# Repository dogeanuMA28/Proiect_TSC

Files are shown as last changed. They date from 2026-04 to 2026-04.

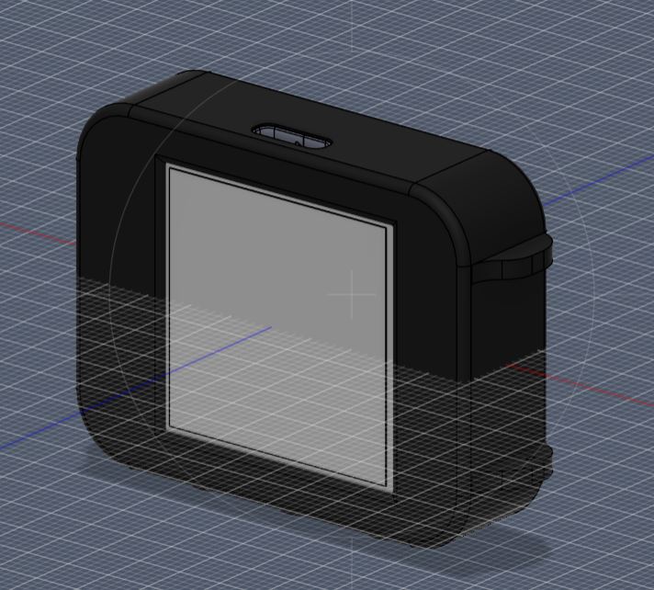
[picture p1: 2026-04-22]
Images/ceas.JPG

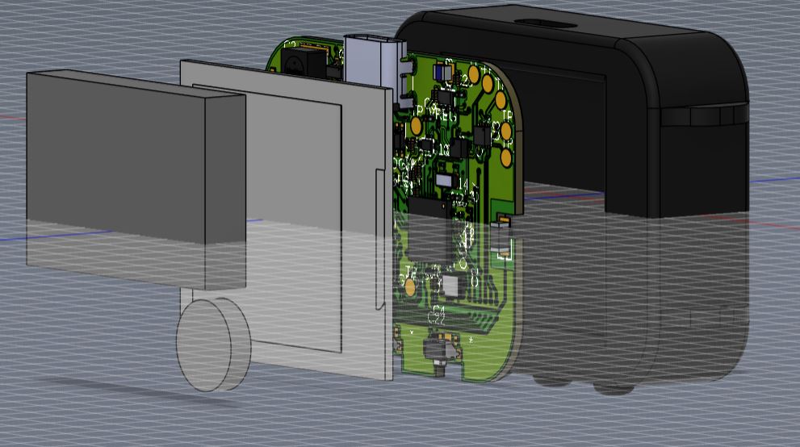
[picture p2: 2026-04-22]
Images/muie_TSC.JPG

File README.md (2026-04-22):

# Proiect_TSC

DIAGRAMA

## BOM(Bill of Materials)
| Componentă | Producator | Cantitate | Link achizitie | Datasheet |
| :--- | :--- | :---: | :--- | :--- |
| **nRF52840** | Nordic Semiconductor | 1 | [Link](https://jlcpcb.com/partdetail/NordicSemicon-NRF52840_QFAA_FR/C3606918) | [Datasheet](https://infocenter.nordicsemi.com/pdf/nRF52840_PS_v1.1.pdf) |
| **BMA423** | Bosch | 1 | [Link](https://jlcpcb.com/partdetail/BoschSensortec-BMA423/C189517) | [Datasheet](https://www.bosch-sensortec.com/media/boschsensortec/downloads/datasheets/bst-bma423-ds004.pdf) |
| **BQ25180YBGR** | Texas Instruments | 1 | [Link](https://jlcpcb.com/partdetail/TexasInstruments-BQ25180YBGR/C3682423) | [Datasheet](https://www.ti.com/lit/ds/symlink/bq25180.pdf) |
| **MAX17048G+T10** | Analog Devices | 1 | [Link](https://jlcpcb.com/partdetail/2777647-MAX17048GT10/C2682616) | [Datasheet](https://datasheets.maximintegrated.com/en/ds/MAX17048-MAX17049.pdf) |
| **DRV2605YZFR** | Texas Instruments | 1 | [Link](https://jlcpcb.com/partdetail/TexasInstruments-DRV2605YZFR/C81079) | [Datasheet](https://www.ti.com/lit/ds/symlink/drv2605.pdf) |
| **RT6160AWSC** | Richtek | 1 | [Link](https://jlcpcb.com/partdetail/RichtekTech-RT6160AWSC/C7065276) | [Datasheet](https://www.richtek.com/assets/product_file/RT6160/DS6160-03.pdf) |
| **2450AT18B100E** | Johanson | 1 | [Link](https://jlcpcb.com/partdetail/JohansonDielectrics-2450AT18B100E/C2917717) | [Datasheet](https://www.johansontechnology.com/datasheets/2450AT18B100E/2450AT18B100E.pdf) |
| **744043680 (L4)** | Wurth | 1 | [Link](https://jlcpcb.com/partdetail/WurthElektronik-744043680/C2045671) | [Datasheet](https://www.we-online.com/catalog/datasheet/744043680.pdf) |
| **FTC252012SR47** | CMT | 1 | [Link](https://jlcpcb.com/partdetail/6763488-FTC252012SR47MBCA/C5832368) | [Datasheet](https://product.tdk.com/en/system/files/dam/doc/product/inductor/inductor/smd/catalog/inductor_commercial_power_ftc252012s_en.pdf) |
| **503480-2400** | Molex | 1 | [Link](https://jlcpcb.com/partdetail/MOLEX-5034802400/C122434) | [Datasheet](https://www.molex.com/pdm_docs/sd/5034802400_sd.pdf) |
| **USB-C 16P** | Kinghelm | 1 | [Link](https://jlcpcb.com/partdetail/Shenzhen_KinghelmElec-KH_TYPE_C16P/C709357) | [Datasheet](https://datasheet.lcsc.com/lcsc/2112151030_Kinghelm-KH-TYPE-C-16P_C2930266.pdf) |
| **EVP-AKE31A** | Panasonic | 3 | [Link](https://jlcpcb.com/partdetail/PANASONIC-EVPAKE31A/C569760) | [Datasheet](https://industrial.panasonic.com/ww/products/pt/tactile-sw/models/EVPAKE31A) |
| **USBLC6-2SC6Y** | STMicroelectronics | 1 | [Link](https://jlcpcb.com/partdetail/STMicroelectronics-USBLC62SC6Y/C2969755) | [Datasheet](https://www.st.com/resource/en/datasheet/usblc6-2.pdf) |
| **MBR0530** | JCET | 3 | [Link](https://jlcpcb.com/partdetail/78464-MBR0530/C77336) | [Datasheet](https://www.onsemi.com/pdf/datasheet/mbr0530t1-d.pdf) |
| **SI1308EDL** | Vishay | 1 | [Link](https://jlcpcb.com/partdetail/VishayIntertech-SI1308EDL_T1GE3/C469327) | [Datasheet](https://www.vishay.com/docs/72013/si1308edl.pdf) |
| **DMG2305UX-7** | TECH PUBLIC | 1 | [Link](https://jlcpcb.com/partdetail/TECHPUBLIC-DMG2305UX/C2940629) | [Datasheet](https://www.diodes.com/assets/Datasheets/DMG2305UX.pdf) |
| **GRM0335C1E101JA01D** | Murata Electronics | 10 | [Link](https://jlcpcb.com/partdetail/MurataElectronics-GRM0335C1E101JA01D/C76917) | [Datasheet](https://docs.rs-online.com/3c16/A700000008615521.pdf) |
| **Condensatoare(0402)** | Samsung Electro-Mechanics | 21 | [Link](https://jlcpcb.com/partdetail/Samsung_Electro_Mechanics-CL05A105KB5NQNC/C52923) | [Datasheet](https://www1.futureelectronics.com/doc/Samsung%20Electro-Mechanics/CL05A105KA5NQNC-SMP.pdf) |
| **Condensatoare(0201)** | Samsung Electro-Mechanics | 17 | [Link](https://jlcpcb.com/partdetail/Murata_Electronics-GRM033R61A104KE84D/C1619) | [Datasheet](https://docs.rs-online.com/3c16/A700000008615521.pdf) |
| **Rezistente(0201)** | UNI-ROYAL | 17 | [Link](https://jlcpcb.com/parts/componentSearch?searchTxt=0201%20resistor) | [Datasheet](https://jlcpcb.com/api/file/downloadByFileSystemAccessId/8590910972175327232) |

## Functionalitati hardware

### LiPo Charger
Circuitul incarca o baterie LiPo (Lithium-Polymer), controland tensiunea si curentul pentru a preveni supraincarcarea, deteriorarea sau riscul de incendiu. Comunica folosind I2C cu nRF52840.

### Fuel Gauge
Circuitul masoara nivelului bateriei. El alerteaza ceasul cand nivelul bateriei este scazut. Comunica folosind I2C cu nRF52840.

### DC/DC
Circuitul alimenteaza si transforma tensiunea in alte tensiuni stabile, necesare pentru alte componente ale ceasului. Comunica folosind 
I2C cu nRF52840.

### E-Paper Connector
Circuitul este conexiunea la ecranul E-Paper. Comunica folosind SPI cu nRF52840.

### E-Paper Drive Circuit
Circuit de comanda care genereaza si controleaza tensiunile si semnalele necesare pentru a actualiza un afisaj E-Paper. Gestioneaza
procesul de schimbare al pixelilor pentru a afisaj.

### USB-C Connector
Circuitul reprezintă mufa USB. Asigura alimentare, transfer de date si semnal video între dispozitive.

### ESD Protection
Circuitul protejează electronica sensibila din USB impotriva descarcarilor electrostatice bruste, limitand tensiunile mari și devierea
curentului către masa pentru a preveni deteriorarea componentelor.

### SWD
Circuitul este folosit pentru debugging. Poate fi conectat la JTAG.

### Haptic Driver
Circuitul genereaza vibratii, transformand semnale digitale din microcontroler in impulsuri precise de vibratie. Comunica folosind I2C cu 
nRF52840.

### IMU
Circuitul masoara acceleratia si directia ceasului. Comunica folosind I2C cu nRF52840.

## nRF52840 - descrierea pinilor
* **P$AD12 (EPD_BUSY)** - conexiune care arata daca ecranul este ocupat (E-Paper Display)
* **P$AD10 (EPD_DC)** - conexiune data/command(E-Paper Display)
* **P$K2 (EPD_CS)** - conexiune chip select(E-Paper Display)
* **P$AD12 (EPD_RST)** - conexiune pentru resetare(E-Paper Display)
* **P$A12 (SCK)** - clock SPI(E-Paper Display)
* **P$P13 (MOSI)** - data(master out slave in) SPI(E-Paper Display).
* **P$Y23 (P1.01)** - conexiune circuit de comanda
* **P$AD8 (P0.13)** - buton din stanga
* **P$AC9 (P0.14)** - buton din mijloc
* **P$W24 (P1.02)** - buton din dreapta
* **P$AD6 (D+)** - traseu diferențial pozitiv pentru ESD Protection
* **P$AD4 (D-)** - traseu diferențial negativ pentru ESD Protection.
* **P$AD2 (VBUS)** - conexiune VBUS(USB)
* **P$U1 (HAPTIC_EN)** - conexiune enable/disable(Haptic Driver)
* **P$T2 (PMIC_INT)** - intrerupere(LiPo Battery)
* **P$P2 (IMU_INT2)** - intrerupere(IMU)
* **P$N1 (IMU_INT1)** - intrerupere(IMU)
* **P$M2 (SCL)** - clock I2C
* **P$L1 (SDA)** - data I2C
* **P$J24 (ALERT)** - conexiune cu alerta(Fuel Gauge)
* **P$AD22 (SWO)** - conexiune pentru debug(TP_SWO)
* **P$AC13 (RESET)** - conexiune pentru resetarea componentei(TP_RESET, SWD)
* **P$AA24 (SWDCLK)** - conexiune pentru debug(SWD)
* **P$AC24 (SWDIO)** - conexiune input/output(SWD)
* **P$F2 și P$D2** - ceasul de 32 kHz
* **P$A23 și P$A24** - ceasul de 32 MHz
* **P$H23, P$F23** - conexiune antena antenă.

## Rutare

Cablajul imprimat (PCB) este realizat pe **4 straturi (4-layer stack-up)**:
* **Top** – rutarea semnalelor si plasarea componentelor
* **GND** – plan de masa continuu (GND)
* **Power** – plan de alimentare
* **Bottom** – rutarea semnalelor

**DC/DC**, **LiPo Charger** si **Fuel Gauge** le-am pozitionat apropiate pentru a oferi un transfer transfer de putere cat mai eficient.
**E-Paper Drive Circuit** a fost izolat in partea de stanga sus(dar tot aproape de **E-Paper Display Connector**) pentru a evita zgomotele
care ar putea fi produse de bobina si care ar putea afecta semnalel SPI, busy sau reset din **E-Paper Display Connector**.
**Haptic Driver** este tinut la distanta de IMU pentru a preveni interferentele din cauza vibratiilor.

## Erori

### via-smd
Am acceptat erorile astea pentru a majoritatea provin din faptul ca am facut vi-in-pad pentru GND.

### smd-via
Le-am acceptat pentru ca fie vin din acelasi motiv ca erorile de mai sus fie de la nRF52840 pentru ca a trebuit
sa pun via-in-pad pentru a conecta cu intrarile de mai din interior.

### solid-poligon-shape
Sunt erori de la butoane. Cred ca este de la disignul lor si nu le pot rezolva.

### via-via
Acestea provin tot de la nRF52840, tot pe intrarile de mai din interior. Le-am acceptat pentru ca altfel nu puteam
conecta firele pentru ca spatiul era mult prea mic.

### via, drill size
Tot ca mai sus. Am fost nevoit sa folosesc via pentru a conecta firele. Spatiul fiid prea mic a trabuit sa
folosesc drill size mai mic de 0.3mm cum precizeaza rule-urile.

### smd-hole
Problema vine de la USB. Tot designul este prblema. Nu am stiut cum sa rezolv aceasta problema fara sa modific
efectiv designul componentei.

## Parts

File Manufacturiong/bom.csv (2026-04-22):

Reference Designators | Quantity | Description | Package | Value | Manufacturer | Manufacturer Part Number | Vendor | Vendor Part Number | Top/Bottom
 | 1 | Board | Board
ANT1 | 1 | Antennas 2.45GHz ANTENNA | 2450AT18B100E_ANTC3216X140N | 2450AT18B100E |  |  |  |  | Top
C1 | 1 | Generic chip capacitor | NORDIC_NRF_3_RESC0201_L | 12pF |  |  |  |  | Top
C1-EP-DR | 1 | Generic chip capacitor | NORDIC_NRF_3_RESC0402_L | 10uF |  |  |  |  | Top
C2 | 1 | Generic chip capacitor | NORDIC_NRF_3_RESC0201_L | 12pF |  |  |  |  | Top
C2-EP-DR | 1 | Generic chip capacitor | NORDIC_NRF_3_RESC0402_L | 4.7uF/25V |  |  |  |  | Top
C3 | 1 | Generic chip capacitor | NORDIC_NRF_3_RESC0201_L | 1pF |  |  |  |  | Top
C4 | 1 | Generic chip capacitor | NORDIC_NRF_3_RESC0201_L | 1pF |  |  |  |  | Top
C5 | 1 | Generic chip capacitor | NORDIC_NRF_3_RESC0201_L | 100nF |  |  |  |  | Top
C6 | 1 | Generic chip capacitor | NORDIC_NRF_3_RESC0402_L | 4.7uF |  |  |  |  | Top
C7 | 1 | Generic chip capacitor | NORDIC_NRF_3_RESC0201_L | 100nF |  |  |  |  | Top
C8 | 1 | Generic chip capacitor | NORDIC_NRF_3_RESC0201_L | 100nF |  |  |  |  | Top
C9 | 1 | Generic chip capacitor | NORDIC_NRF_3_RESC0201_L | 820pF |  |  |  |  | Top
C10 | 1 | Generic chip capacitor | NORDIC_NRF_3_RESC0201_L | N.C. |  |  |  |  | Top
C11 | 1 | Generic chip capacitor | NORDIC_NRF_3_RESC0201_L | 100pF |  |  |  |  | Top
C12 | 1 | Generic chip capacitor | NORDIC_NRF_3_RESC0201_L | 100nF |  |  |  |  | Top
C13 | 1 | Generic chip capacitor | NORDIC_NRF_3_RESC0201_L | N.C. |  |  |  |  | Top
C14 | 1 | Generic chip capacitor | NORDIC_NRF_3_RESC0402_L | 4.7uF |  |  |  |  | Top
C15 | 1 | Generic chip capacitor | NORDIC_NRF_3_RESC0402_L | 1.0uF |  |  |  |  | Top
C16 | 1 | Generic chip capacitor | NORDIC_NRF_3_RESC0201_L | 47nF |  |  |  |  | Top
C17 | 1 | Generic chip capacitor | NORDIC_NRF_3_RESC0201_L | 12pF |  |  |  |  | Top
C18 | 1 | Generic chip capacitor | NORDIC_NRF_3_RESC0201_L | 12pF |  |  |  |  | Top
C19 | 1 | Generic chip capacitor | NORDIC_NRF_3_RESC0201_L | 100nF |  |  |  |  | Top
C20 | 1 | Generic chip capacitor | NORDIC_NRF_3_RESC0402_L | 4.7uF |  |  |  |  | Top
C21 | 1 | Generic chip capacitor | NORDIC_NRF_3_RESC0402_L | 4.7uF |  |  |  |  | Top
C22 | 1 | Generic chip capacitor | NORDIC_NRF_3_RESC0201_L | N.C. |  |  |  |  | Top
C23 | 1 | Check availability | NORDIC_NRF_3_RESC0201_L | 0.1uF |  |  |  |  | Top
C24 | 1 | Generic chip capacitor | NORDIC_NRF_3_RESC0402_L | 10uF |  |  |  |  | Top
C25 | 1 | Generic chip capacitor | NORDIC_NRF_3_RESC0402_L | 22uF |  |  |  |  | Top
C27 | 1 | Check availability | NORDIC_NRF_3_RESC0201_L | 0.1uF |  |  |  |  | Top
C29 | 1 | Check availability | NORDIC_NRF_3_RESC0201_L | 1uF |  |  |  |  | Top
C30 | 1 | Check availability | NORDIC_NRF_3_RESC0201_L | 1uF |  |  |  |  | Top
C31 | 1 | Check availability | NORDIC_NRF_3_RESC0201_L | 1uF |  |  |  |  | Top
C32 | 1 | Check availability | NORDIC_NRF_3_RESC0201_L | 1uF |  |  |  |  | Top
C33 | 1 | Generic chip capacitor | NORDIC_NRF_3_RESC0402_L | 22uF |  |  |  |  | Top
C34 | 1 | Check availability | NORDIC_NRF_3_RESC0201_L | 0.1uF |  |  |  |  | Top
C37 | 1 | Check availability | NORDIC_NRF_3_RESC0201_L | 1uF |  |  |  |  | Top
C38 | 1 | Check availability | NORDIC_NRF_3_RESC0201_L | 1uF |  |  |  |  | Top
C39 | 1 | Generic chip capacitor | NORDIC_NRF_3_RESC0402_L | 10uF |  |  |  |  | Top
C42 | 1 | Check availability | NORDIC_NRF_3_RESC0201_L | 0.1uF |  |  |  |  | Top
C43 | 1 | Generic chip capacitor | NORDIC_NRF_3_RESC0402_L | 4.7uF |  |  |  |  | Top
D2 | 1 | ON SEMICONDUCTOR - MBR0530 - DIODE, SCHOTTKY, 0.5A, 30V, SOD-123 | ESP32_C6_LIBRARY_5_SOD3716X135N | MBR0530 |  |  |  |  | Top
D3 | 1 | Low Cap. ESD Protection Auto SOT-23-6 STMicroelectronics USBLC6-2SC6Y, Dual Uni-Directional TVS Diode Array, 6-Pin SOT-23 | ESP32_C6_LIBRARY_3_SOT95P280X145-6N | USBLC6-2SC6Y |  |  |  |  | Top
D4 | 1 | ON SEMICONDUCTOR - MBR0530 - DIODE, SCHOTTKY, 0.5A, 30V, SOD-123 | ESP32_C6_LIBRARY_5_SOD3716X135N | MBR0530 |  |  |  |  | Top
D5 | 1 | ON SEMICONDUCTOR - MBR0530 - DIODE, SCHOTTKY, 0.5A, 30V, SOD-123 | ESP32_C6_LIBRARY_5_SOD3716X135N | MBR0530 |  |  |  |  | Top
EPD_C1 | 1 | Generic chip capacitor | NORDIC_NRF_3_RESC0402_L | 1uF/50V |  |  |  |  | Top
EPD_C2 | 1 | Generic chip capacitor | NORDIC_NRF_3_RESC0402_L | 1uF/50V |  |  |  |  | Top
EPD_C5 | 1 | Generic chip capacitor | NORDIC_NRF_3_RESC0201_L | 0.1uF/50V |  |  |  |  | Top
EPD_C6 | 1 | Generic chip capacitor | NORDIC_NRF_3_RESC0402_L | 1uF/50V |  |  |  |  | Top
EPD_C7 | 1 | Generic chip capacitor | NORDIC_NRF_3_RESC0402_L | 1uF/50V |  |  |  |  | Top
EPD_C8 | 1 | Generic chip capacitor | NORDIC_NRF_3_RESC0402_L | 1uF/50V |  |  |  |  | Top
EPD_C9 | 1 | Generic chip capacitor | NORDIC_NRF_3_RESC0402_L | 1uF/50V |  |  |  |  | Top
EPD_C10 | 1 | Generic chip capacitor | NORDIC_NRF_3_RESC0402_L | 1uF/50V |  |  |  |  | Top
EPD_C11 | 1 | Generic chip capacitor | NORDIC_NRF_3_RESC0402_L | 1uF/50V |  |  |  |  | Top
EPD_C12 | 1 | Generic chip capacitor | NORDIC_NRF_3_RESC0402_L | 1uF/50V |  |  |  |  | Top
IC1 | 1 | Charger IC Lithium Ion/Polymer, Lithium Iron Phosphate 8-DSBGA (1.6x1.1) | BQ25180YBGR_BGA8C40P2X4_100X155X50 | BQ25180YBGR |  |  |  |  | Top
IC2 | 1 | Haptic Driver for ERM/LRA with Built-In Library and Smart Loop Architecture | DRV2605YZFR_BGA9C50P3X3_144X144X62-HAPTIC | DRV2605YZFR |  |  |  |  | Top
IC3 | 1 | Accelerometers Triaxial low-g 12bit Acceleration Sensor | IMU_BMA423 | BMA423_BMA423 |  |  |  |  | Top
IC9 | 1 | Buck-Boost Regulator Positive Output Step-Up/Step-Down I2C DC-DC Controller IC 15-WL-CSP (BSC) (1.4x2.3) | RT6160AWSC_BGA15C40P3X5_140X230X60 | RT6160AWSC |  |  |  |  | Top
J1 | 1 | FFC & FPC Connectors 0.5mm FPC RA SMT Dual Contact 24Ckt | 503480-2400 | 503480-2400 |  |  |  |  | Top
J2 | 1 | CABLE ADAPTER 6 POS | TC2030-IDC_TC2030IDC | TC2030-IDC |  |  |  |  | Top
J4 | 1 | Check availability | KH-TYPE-C-16P_KINGHELM_KH-TYPE-C-16P | KH-TYPE-C-16P |  |  |  |  | Top
L1 | 1 | Generic chip inductor | NORDIC_NRF_3_RESC0402_L | 3.9nH |  |  |  |  | Top
L2 | 1 | Generic chip inductor | NORDIC_NRF_3_RESC0201_L | 10uH |  |  |  |  | Top
L3 | 1 | Generic chip inductor | NORDIC_NRF_3_RESC0201_L | 15nH |  |  |  |  | Top
L5 | 1 |  | ESP32_C6_LIBRARY_2_IND_4828-WE-TPC_WRE | 48uH |  |  |  |  | Top
L7 | 1 | SMD / SMT Inductors (Coils), L=0.47?H, L x W x T : | MLP2016SR47MT0S1_INDC2016X100N | FTC252012SR47MBCA |  |  |  |  | Top
Q1 | 1 | P-channel MOSFETs | ESP32_C6_LIBRARY_4_ESP32_WROVER_SPARKFUN-DISCRETESEMI_SOT23-3 | 20V/4.2A/52mΩ/1.4W |  |  |  |  | Top
Q3 | 1 | MOSFET N-Ch 30V 1.5A TrenchFET SC70 Vishay Si1308EDL-T1-GE3 N-channel MOSFET Transistor, 1.5 A, 30 V, 3-Pin SC-70 | ESP32_C6_LIBRARY_6_SOT65P210X110-3N | SI1308EDL-T1-GE3 |  |  |  |  | Top
R_PWR_EPD | 1 | 7.68k 0201 Thin Film Surface Mount Fixed Resistor +/-0.5% 0.031W CPF0201D7K68C1 | RES_0201 | 10k |  |  |  |  | Top
R_TYPE_SEL | 1 | 7.68k 0201 Thin Film Surface Mount Fixed Resistor +/-0.5% 0.031W CPF0201D7K68C1 | RES_0201 | 2.2 |  |  |  |  | Top
R1_EP_DR | 1 | 7.68k 0201 Thin Film Surface Mount Fixed Resistor +/-0.5% 0.031W CPF0201D7K68C1 | RES_0201 | 0.47 |  |  |  |  | Top
R1_USB | 1 | 7.68k 0201 Thin Film Surface Mount Fixed Resistor +/-0.5% 0.031W CPF0201D7K68C1 | RES_0201 | 5K1 |  |  |  |  | Top
R2 | 1 | 7.68k 0201 Thin Film Surface Mount Fixed Resistor +/-0.5% 0.031W CPF0201D7K68C1 | RES_0201 | 0 |  |  |  |  | Top
R2_EP_DR | 1 | 7.68k 0201 Thin Film Surface Mount Fixed Resistor +/-0.5% 0.031W CPF0201D7K68C1 | RES_0201 | 10k |  |  |  |  | Top
R2_USB | 1 | 7.68k 0201 Thin Film Surface Mount Fixed Resistor +/-0.5% 0.031W CPF0201D7K68C1 | RES_0201 | 5K1 |  |  |  |  | Top
R3 | 1 | 7.68k 0201 Thin Film Surface Mount Fixed Resistor +/-0.5% 0.031W CPF0201D7K68C1 | RES_0201 | 0 |  |  |  |  | Top
R4 | 1 | 7.68k 0201 Thin Film Surface Mount Fixed Resistor +/-0.5% 0.031W CPF0201D7K68C1 | RES_0201 | 0 |  |  |  |  | Top
R5 | 1 | 7.68k 0201 Thin Film Surface Mount Fixed Resistor +/-0.5% 0.031W CPF0201D7K68C1 | RES_0201 | 10k |  |  |  |  | Top
R7 | 1 | 7.68k 0201 Thin Film Surface Mount Fixed Resistor +/-0.5% 0.031W CPF0201D7K68C1 | RES_0201 | 10k |  |  |  |  | Top
R8 | 1 | 7.68k 0201 Thin Film Surface Mount Fixed Resistor +/-0.5% 0.031W CPF0201D7K68C1 | RES_0201 | 10k |  |  |  |  | Top
R9 | 1 | 7.68k 0201 Thin Film Surface Mount Fixed Resistor +/-0.5% 0.031W CPF0201D7K68C1 | RES_0201 | 10K |  |  |  |  | Top
R17 | 1 | 7.68k 0201 Thin Film Surface Mount Fixed Resistor +/-0.5% 0.031W CPF0201D7K68C1 | RES_0201 | 3k3 |  |  |  |  | Top
R18 | 1 | 7.68k 0201 Thin Film Surface Mount Fixed Resistor +/-0.5% 0.031W CPF0201D7K68C1 | RES_0201 | 3K3 |  |  |  |  | Top
SJ1 | 1 | SMD solder JUMPER | JUMPER_SJ |  |  |  |  |  | Top
SW_DN | 1 |  | SW_EVP-AKE31A_PAN | EVP-AKE31A_PAN |  |  |  |  | Top
SW_ENT | 1 |  | SW_EVP-AKE31A_PAN | EVP-AKE31A_PAN |  |  |  |  | Top
SW_UP | 1 |  | SW_EVP-AKE31A_PAN | EVP-AKE31A_PAN |  |  |  |  | Top
TP_3.3V | 1 | Test pad | HECTOR_WATCH_1_TP20R | HECTOR_WATCH_1_TPTP20R |  |  |  |  | Top
TP_3V3 | 1 | Test pad | HECTOR_WATCH_1_TP20R | HECTOR_WATCH_1_TPTP20R |  |  |  |  | Top
TP_BAT_GND | 1 | Test pad | HECTOR_WATCH_1_TP20R | HECTOR_WATCH_1_TPTP20R |  |  |  |  | Top
TP_GND | 1 | Test pad | HECTOR_WATCH_1_TP20R | HECTOR_WATCH_1_TPTP20R |  |  |  |  | Top
TP_ON | 1 | Test pad | HECTOR_WATCH_1_TP20R | HECTOR_WATCH_1_TPTP20R |  |  |  |  | Top
TP_OP | 1 | Test pad | HECTOR_WATCH_1_TP20R | HECTOR_WATCH_1_TPTP20R |  |  |  |  | Top
TP_RESET | 1 | Test pad | HECTOR_WATCH_1_TP20R | HECTOR_WATCH_1_TPTP20R |  |  |  |  | Top
TP_SCL | 1 | Test pad | HECTOR_WATCH_1_TP20R | HECTOR_WATCH_1_TPTP20R |  |  |  |  | Top
TP_SDA | 1 | Test pad | HECTOR_WATCH_1_TP20R | HECTOR_WATCH_1_TPTP20R |  |  |  |  | Top
TP_SWDCLK | 1 | Test pad | HECTOR_WATCH_1_TP20R | HECTOR_WATCH_1_TPTP20R |  |  |  |  | Top
TP_SWDIO | 1 | Test pad | HECTOR_WATCH_1_TP20R | HECTOR_WATCH_1_TPTP20R |  |  |  |  | Top
TP_SWO | 1 | Test pad | HECTOR_WATCH_1_TP20R | HECTOR_WATCH_1_TPTP20R |  |  |  |  | Top
TP_VBAT | 1 | Test pad | HECTOR_WATCH_1_TP20R | HECTOR_WATCH_1_TPTP20R |  |  |  |  | Top
TP_VREG | 1 | Test pad | HECTOR_WATCH_1_TP20R | HECTOR_WATCH_1_TPTP20R |  |  |  |  | Top
U1 | 1 | nRF52840 | NORDIC_NRF_4_AQFN50P700X700X85_HS-74N | NRF52840_QF |  |  |  |  | Top
U3 | 1 | Check availability | ESP32_C6_LIBRARY_SON50P200X200X80-9N | MAX17048G+T10 |  |  |  |  | Top
X1 | 1 |  | NORDIC_NRF_BT-XTAL_2016_N | 32MHz |  |  |  |  | Top
X2 | 1 |  | NORDIC_NRF_1_XTAL_3215_N | 32.768kHz |  |  |  |  | Top

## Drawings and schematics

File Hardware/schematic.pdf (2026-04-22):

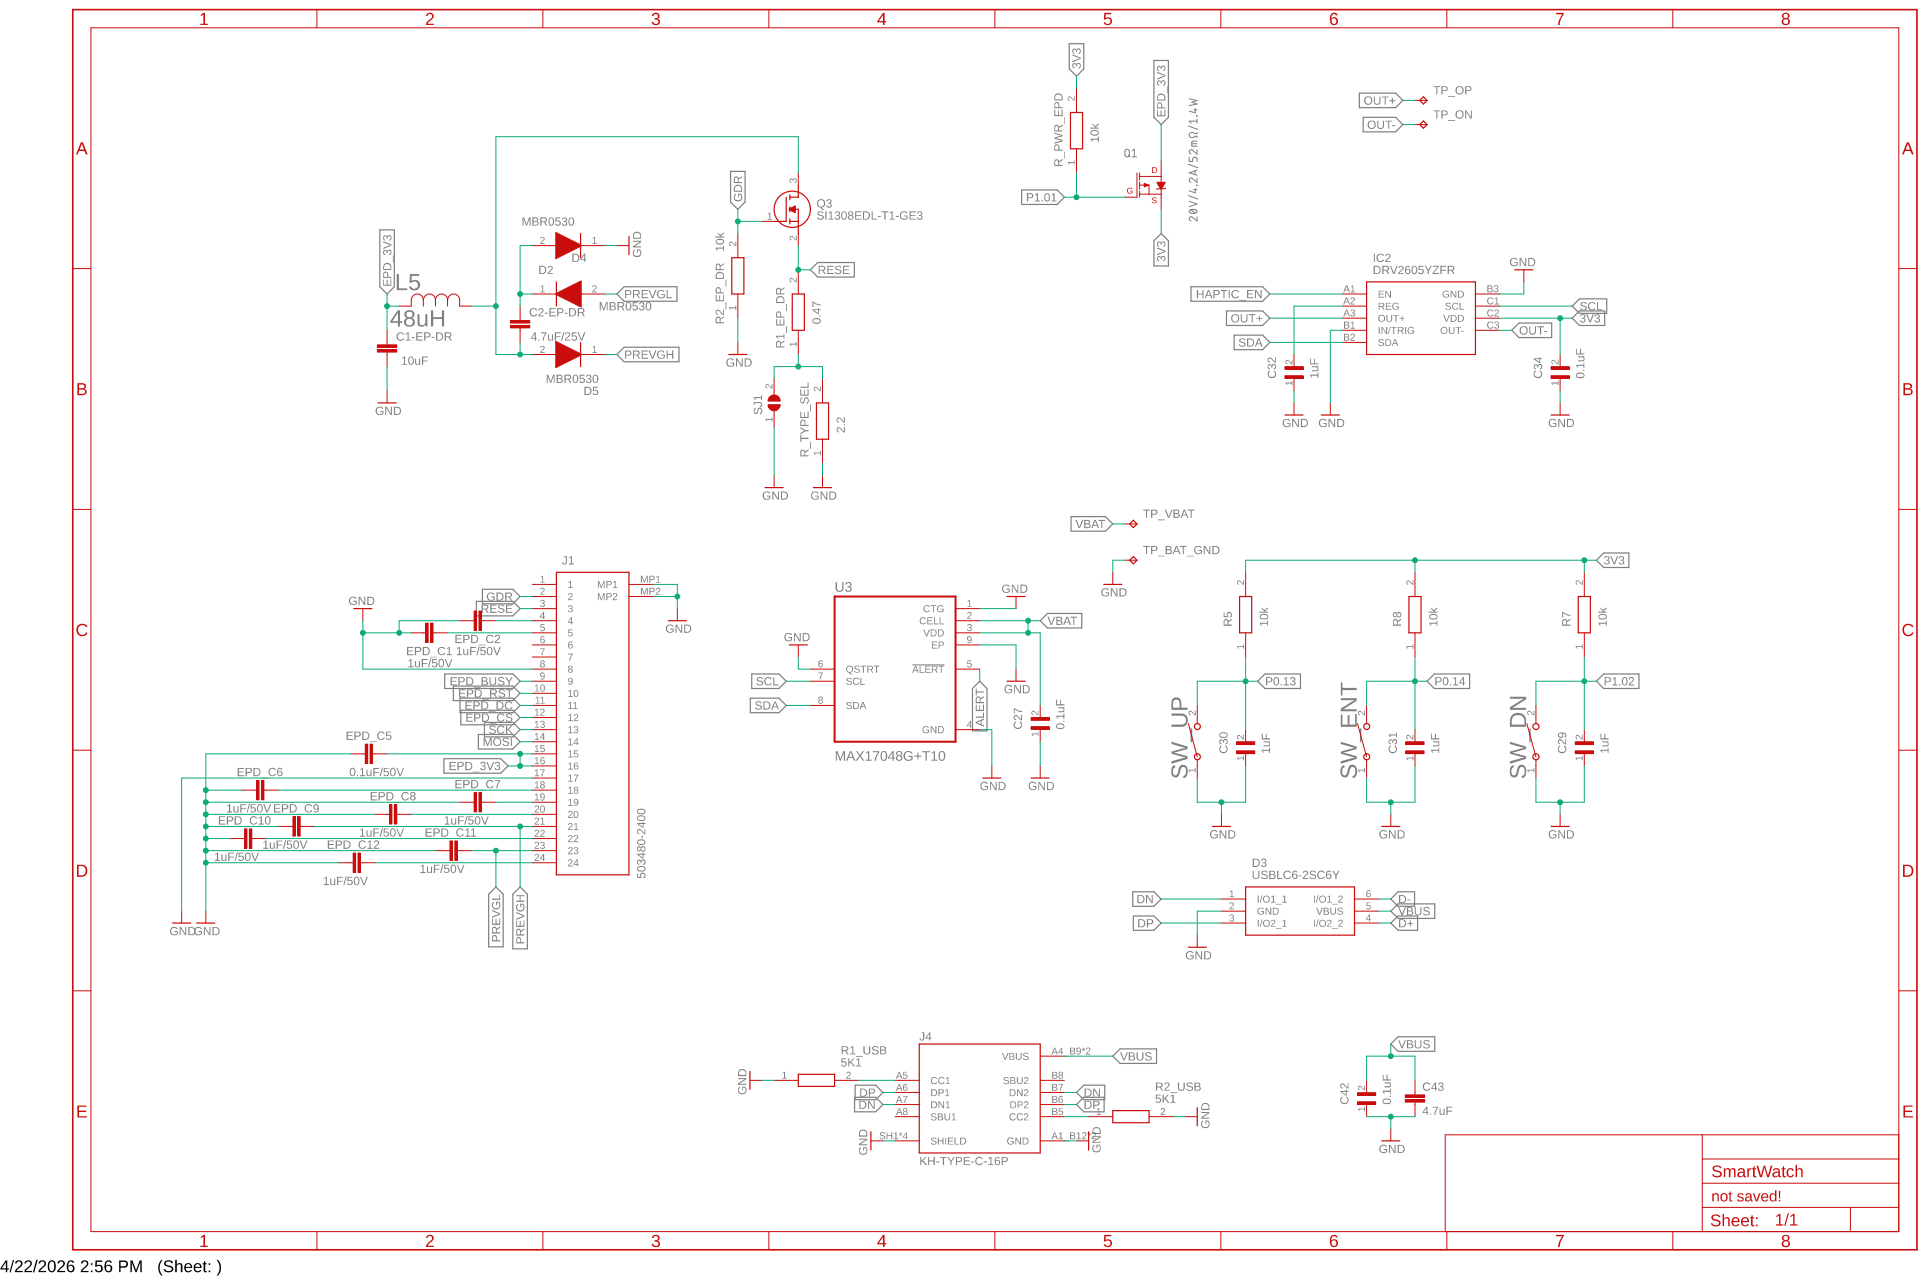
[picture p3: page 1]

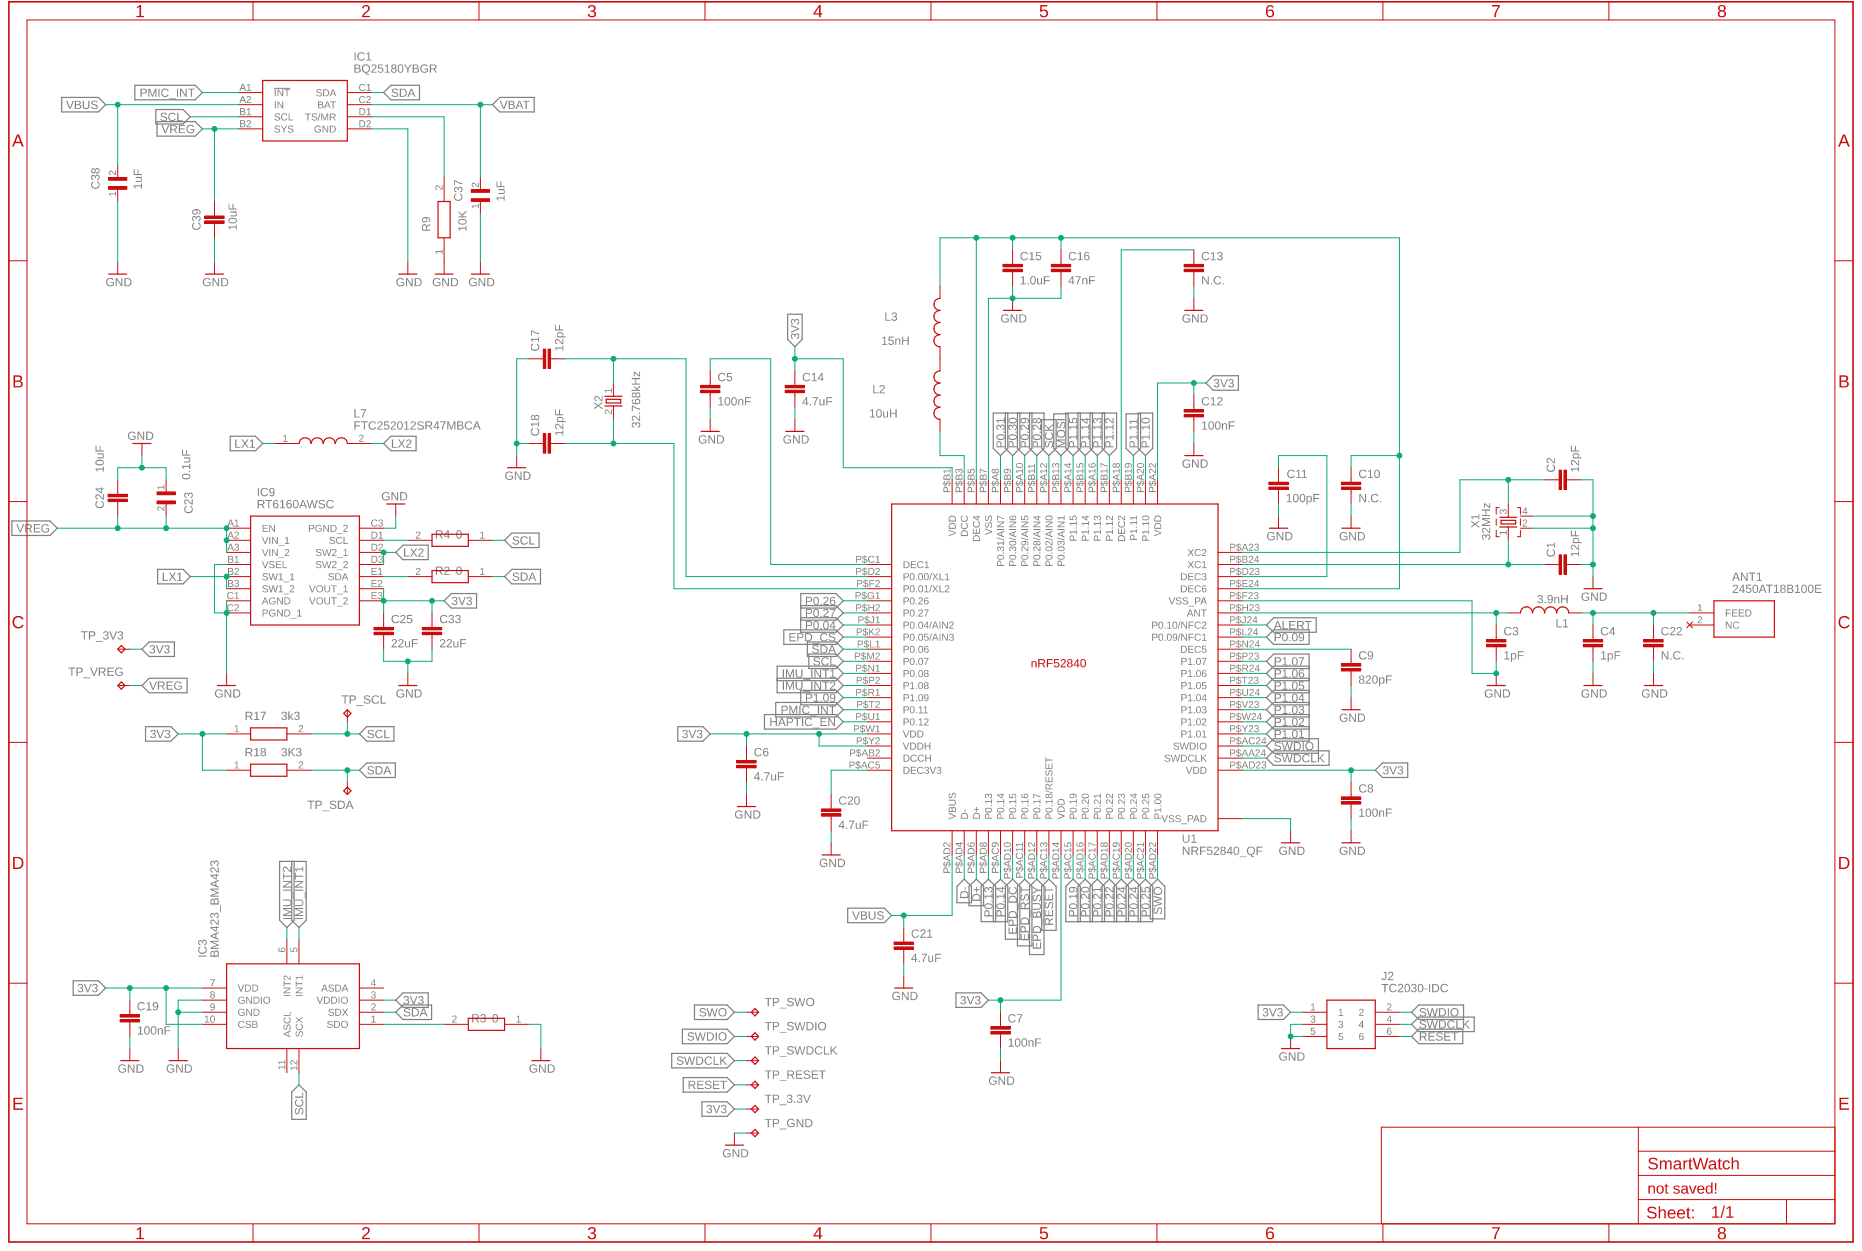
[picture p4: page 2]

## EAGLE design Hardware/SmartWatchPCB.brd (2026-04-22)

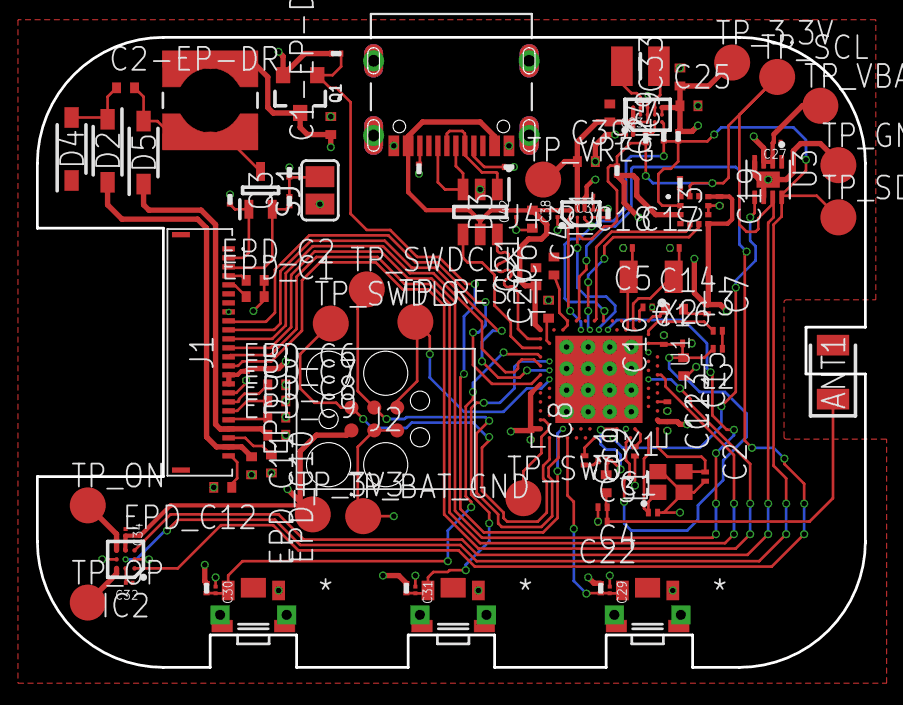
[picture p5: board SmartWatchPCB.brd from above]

Board: 4 copper layers, 46.0 x 35.0 mm, 105 parts (0 on the bottom side), 73 nets.

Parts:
ANT1: 2450AT18B100E; 2450AT18B100E_ANTC3216X140N
C1, C2, C17, C18: 12pF; NORDIC_NRF_3_RESC0201_L
C1-EP-DR, C24, C39: 10uF; NORDIC_NRF_3_RESC0402_L
C2-EP-DR: 4.7uF/25V; NORDIC_NRF_3_RESC0402_L
C3, C4: 1pF; NORDIC_NRF_3_RESC0201_L
C5, C7, C8, C12, C19: 100nF; NORDIC_NRF_3_RESC0201_L
C6, C14, C20, C21, C43: 4.7uF; NORDIC_NRF_3_RESC0402_L
C9: 820pF; NORDIC_NRF_3_RESC0201_L
C10, C13, C22: N.C.; NORDIC_NRF_3_RESC0201_L
C11: 100pF; NORDIC_NRF_3_RESC0201_L
C15: 1.0uF; NORDIC_NRF_3_RESC0402_L
C16: 47nF; NORDIC_NRF_3_RESC0201_L
C23, C27, C34, C42: 0.1uF; GRM011R60J152KE01L_2_CAPC0201X13N
C25, C33: 22uF; NORDIC_NRF_3_RESC0402_L
C29, C30, C31, C32, C37, C38: 1uF; GRM011R60J152KE01L_2_CAPC0201X13N
D2, D4, D5: MBR0530; ESP32_C6_LIBRARY_5_SOD3716X135N
D3: USBLC6-2SC6Y; ESP32_C6_LIBRARY_3_SOT95P280X145-6N
EPD_C1, EPD_C2, EPD_C6, EPD_C7, EPD_C8, EPD_C9, EPD_C10, EPD_C11, EPD_C12: 1uF/50V; NORDIC_NRF_3_RESC0402_L
EPD_C5: 0.1uF/50V; NORDIC_NRF_3_RESC0201_L
IC1: BQ25180YBGR; BQ25180YBGR_BGA8C40P2X4_100X155X50
IC2: DRV2605YZFR; DRV2605YZFR_BGA9C50P3X3_144X144X62
IC3: BMA423_BMA423
IC9: RT6160AWSC; RT6160AWSC_BGA15C40P3X5_140X230X60
J1: 503480-2400; 503480-2400_5034802400
J2: TC2030-IDC; TC2030-IDC_TC2030IDC
J4: KH-TYPE-C-16P; KH-TYPE-C-16P_KINGHELM_KH-TYPE-C-16P
L1: 3.9nH; NORDIC_NRF_2_RESC0402_L
L2: 10uH; NORDIC_NRF_2_RESC0201_L
L3: 15nH; NORDIC_NRF_2_RESC0201_L
L5: 48uH; ESP32_C6_LIBRARY_2_IND_4828-WE-TPC_WRE
L7: FTC252012SR47MBCA; MLP2016SR47MT0S1_INDC2016X100N
Q1: 20V/4.2A/52mΩ/1.4W; ESP32_C6_LIBRARY_4_ESP32_C6_LIBRARY_4_ESP32_C6_LIBRARY_4_ES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
Q3: SI1308EDL-T1-GE3; ESP32_C6_LIBRARY_6_SOT65P210X110-3N
R1_EP_DR: 0.47; CPF0201D7K68C1_0201
R1_USB, R2_USB: 5K1; CPF0201D7K68C1_0201
R2, R3, R4: 0; CPF0201D7K68C1_0201
R2_EP_DR, R5, R7, R8: 10k; CPF0201D7K68C1_0201
R9: 10K; CPF0201D7K68C1_0201
R17: 3k3; CPF0201D7K68C1_0201
R18: 3K3; CPF0201D7K68C1_0201
R_PWR_EPD: 10k; CPF0201D7K68C1_0201
R_TYPE_SEL: 2.2; CPF0201D7K68C1_0201
SJ1: ESP32_C6_LIBRARY_7_JUMPER_SJ
SW_DN: EVP-AKE31A_PAN; 2025-10-22_07-23-44_LIBRARY_SW_EVP-AKE31A_PAN
SW_ENT: EVP-AKE31A_PAN; 2025-10-22_07-23-44_LIBRARY_SW_EVP-AKE31A_PAN
SW_UP: EVP-AKE31A_PAN; 2025-10-22_07-23-44_LIBRARY_SW_EVP-AKE31A_PAN
TP_3.3V, TP_3V3: HECTOR_WATCH_1_TPTP20R; HECTOR_WATCH_1_TP20R
TP_BAT_GND: HECTOR_WATCH_1_TPTP20R; HECTOR_WATCH_1_TP20R
TP_GND: HECTOR_WATCH_1_TPTP20R; HECTOR_WATCH_1_TP20R
TP_ON: HECTOR_WATCH_1_TPTP20R; HECTOR_WATCH_1_TP20R
TP_OP: HECTOR_WATCH_1_TPTP20R; HECTOR_WATCH_1_TP20R
TP_RESET: HECTOR_WATCH_1_TPTP20R; HECTOR_WATCH_1_TP20R
TP_SCL: HECTOR_WATCH_1_TPTP20R; HECTOR_WATCH_1_TP20R
TP_SDA: HECTOR_WATCH_1_TPTP20R; HECTOR_WATCH_1_TP20R
TP_SWDCLK: HECTOR_WATCH_1_TPTP20R; HECTOR_WATCH_1_TP20R
TP_SWDIO: HECTOR_WATCH_1_TPTP20R; HECTOR_WATCH_1_TP20R
TP_SWO: HECTOR_WATCH_1_TPTP20R; HECTOR_WATCH_1_TP20R
TP_VBAT: HECTOR_WATCH_1_TPTP20R; HECTOR_WATCH_1_TP20R
TP_VREG: HECTOR_WATCH_1_TPTP20R; HECTOR_WATCH_1_TP20R
U1: NRF52840_QF; NORDIC_NRF_4_AQFN50P700X700X85_HS-74N
U3: MAX17048G+T10; ESP32_C6_LIBRARY_SON50P200X200X80-9N
X1: 32MHz; NORDIC_NRF_BT-XTAL_2016_N
X2: 32.768kHz; NORDIC_NRF_1_XTAL_3215_N

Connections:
3V3: C7.1, C8.1, C12.1, C19.1, C25.1, C33.1, C34.2, IC2.C2, IC3.3, IC3.7, IC3.10, IC9.E2, IC9.E3, J2.1, Q1.2, R5.2, R7.2, R8.2, R17.1, R18.1, R_PWR_EPD.2, TP_3.3V.TP, TP_3V3.TP, U1.P$A22, U1.P$AD14, U1.P$AD23
ALERT: U1.P$J24, U3.5
D+: D3.4, U1.P$AD6
D-: D3.6, U1.P$AD4
DEC1: C5.1, U1.P$C1
DN: D3.1, J4.A7, J4.B7
DP: D3.3, J4.A6, J4.B6
EPD_3V3: C1-EP-DR.1, EPD_C5.1, J1.15, J1.16, L5.2, Q1.3
EPD_BUSY: J1.9, U1.P$AD12
EPD_CS: J1.12, U1.P$K2
EPD_DC: J1.11, U1.P$AD10
EPD_RST: J1.10, U1.P$AC11
GDR: J1.2, Q3.1, R2_EP_DR.2
GND: C1.2, C1-EP-DR.2, C2.2, C3.2, C4.2, C5.2, C6.2, C8.2, C9.2, C10.2, C11.1, C12.2, C13.2, C15.2, C16.2, C17.1, C18.1, C19.2, C20.2, C21.2, C22.2, C23.1, C24.1, C25.2, C27.1, C29.1, C30.1, C31.1, C32.1, C33.2, C34.1, C37.1, C38.1, C39.2, C42.1, C43.2, D3.2, D4.1, EPD_C1.2, EPD_C2.2, EPD_C5.2, EPD_C6.2, EPD_C7.2, EPD_C8.2, EPD_C9.2, EPD_C10.2, EPD_C11.2, EPD_C12.2, IC1.D2, IC2.B1, IC2.B3, IC3.8, IC3.9, IC9.B1, IC9.C1, IC9.C2, IC9.C3, J1.8, J1.17, J1.MP1, J1.MP2, J2.3, J2.5, J4.A1_B12, J4.A12_B1, J4.SH1, J4.SH2, J4.SH3, J4.SH4, R1_USB.1, R2_EP_DR.1, R2_USB.2, R3.1, R9.1, R_TYPE_SEL.1, SJ1.1, SW_DN.1, SW_ENT.1, SW_UP.1, TP_BAT_GND.TP, TP_GND.TP, U1.P$74, U1.P$75, U1.P$76, U1.P$77, U1.P$78, U1.P$79, U1.P$80, U1.P$81, U1.P$82, U1.P$83, U1.P$84, U1.P$85, U1.P$86, U1.P$87, U1.P$88, U1.P$89, U1.P$90, U1.P$B7, U1.P$F23, U3.1, U3.4, U3.6, U3.9, X1.2, X1.4
HAPTIC_EN: IC2.A1, U1.P$U1
IMU_INT1: IC3.5, U1.P$N1
IMU_INT2: IC3.6, U1.P$P2
LX1: IC9.B2, IC9.B3, L7.1
LX2: IC9.D2, IC9.D3, L7.2
MOSI: J1.14, U1.P$B13
unnamed: IC1.D1, R9.2
unnamed: IC9.D1, R4.2
unnamed: IC9.E1, R2.2
unnamed: IC3.1, R3.2
unnamed: C20.1, U1.P$AC5
unnamed: C17.2, U1.P$D2, X2.1
unnamed: C18.2, U1.P$F2, X2.2
unnamed: C6.1, U1.P$W1, U1.P$Y2
unnamed: C7.2, C14.2
unnamed: C14.1, U1.P$B1
unnamed: L2.1, U1.P$B3
unnamed: L2.2, L3.1
unnamed: C10.1, C15.1, C16.1, L3.2, U1.P$B5, U1.P$E24
unnamed: C1.1, U1.P$B24, X1.1
unnamed: C2.1, U1.P$A23, X1.3
unnamed: C11.2, U1.P$D23
unnamed: C3.1, L1.1, U1.P$H23
unnamed: ANT1.1, C4.1, C22.1, L1.2
unnamed: C9.1, U1.P$N24
unnamed: C2-EP-DR.2, D5.2, L5.1, Q3.3
unnamed: C2-EP-DR.1, D2.1, D4.2
unnamed: EPD_C1.1, J1.5
unnamed: C13.1, U1.P$A18
unnamed: R1_EP_DR.1, R_TYPE_SEL.2, SJ1.2
unnamed: EPD_C2.1, J1.4
unnamed: C32.2, IC2.A2
unnamed: J4.B5, R2_USB.1
unnamed: J4.A5, R1_USB.2
unnamed: EPD_C6.1, J1.18
unnamed: EPD_C7.1, J1.19
unnamed: EPD_C8.1, J1.20
unnamed: EPD_C10.1, J1.22
unnamed: EPD_C12.1, J1.24
OUT+: IC2.A3, TP_OP.TP
OUT-: IC2.C3, TP_ON.TP
P0.13: C30.2, R5.1, SW_UP.2, U1.P$AD8
P0.14: C31.2, R8.1, SW_ENT.2, U1.P$AC9
P1.01: Q1.1, R_PWR_EPD.1, U1.P$Y23
P1.02: C29.2, R7.1, SW_DN.2, U1.P$W24
PMIC_INT: IC1.A1, U1.P$T2
PREVGH: D5.1, EPD_C9.1, J1.21
PREVGL: D2.2, EPD_C11.1, J1.23
RESE: J1.3, Q3.2, R1_EP_DR.2
RESET: J2.6, TP_RESET.TP, U1.P$AC13
SCK: J1.13, U1.P$A12
SCL: IC1.B1, IC2.C1, IC3.12, R4.1, R17.2, TP_SCL.TP, U1.P$M2, U3.7
SDA: IC1.C1, IC2.B2, IC3.2, R2.1, R18.2, TP_SDA.TP, U1.P$L1, U3.8
SWDCLK: J2.4, TP_SWDCLK.TP, U1.P$AA24
SWDIO: J2.2, TP_SWDIO.TP, U1.P$AC24
SWO: TP_SWO.TP, U1.P$AD22
VBAT: C27.2, C37.2, IC1.C2, TP_VBAT.TP, U3.2, U3.3
VBUS: C21.1, C38.2, C42.2, C43.1, D3.5, IC1.A2, J4.A4_B9, J4.A9_B4, U1.P$AD2
VREG: C23.2, C24.2, C39.1, IC1.B2, IC9.A1, IC9.A2, IC9.A3, TP_VREG.TP

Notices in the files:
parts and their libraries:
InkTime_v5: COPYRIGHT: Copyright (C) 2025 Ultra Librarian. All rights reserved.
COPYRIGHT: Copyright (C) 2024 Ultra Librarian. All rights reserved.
